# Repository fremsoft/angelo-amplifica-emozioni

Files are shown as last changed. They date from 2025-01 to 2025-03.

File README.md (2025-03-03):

# ANGELO: Amplifica Emozioni

## La Storia
Luciano Fumagalli, pensionato curioso e amante del pensiero laterale, è l’ideatore di ANGELO, un dispositivo inizialmente pensato per gli anziani ipoacusici delle RSA italiane durante la recente pandemia. Grazie alla sua economicità e condivisione Open Source, ANGELO è adatto anche ai paesi LMIC (Low and Low Middle Income Countries), spesso gravati da un elevato grado di inaccessibilità alla tecnologia.

L'idea di ANGELO nasce dalla passione per la tecnologia e dalla sfida di affrontare problematiche sociali, migliorando l'accesso alle cure uditive per anziani e persone in contesti difficili. Luciano ha utilizzato il pensiero laterale per ideare soluzioni non convenzionali, migliorando la qualità della vita di chi ha difficoltà uditive.

---

## Il Team
Il progetto "ANGELO, amplifica emozioni" è stato possibile grazie alla collaborazione di:
- **Docenti universitari**: hanno fornito conoscenze scientifiche e tecnologiche per delineare road map di sviluppo.
- **Scuole superiori**: hanno coinvolto studenti e docenti nella progettazione e realizzazione di prototipi, poi donati alle RSA.
- **Maker audiofilo**: ha contribuito con competenze sugli amplificatori equalizzati.
- **Hub tecnologici e designer**: hanno sviluppato una cover 3D elegante, ergonomica e facile da assemblare.
- **Società di packaging e artista calligrafico**: hanno realizzato un box su misura con design emozionale.

Grazie a queste sinergie, ANGELO è diventato un dispositivo acustico Open Source innovativo e inclusivo.

---

## Il Progetto
ANGELO è un amplificatore equalizzato, progettato per potenziare selettivamente le frequenze uditive rilevanti, migliorando la comprensione del parlato e la percezione delle emozioni sonore.

Caratteristiche principali:
- **Open Source**: flessibile e scalabile, consente la condivisione di conoscenze e l'innovazione continua.
- **Design intuitivo**: facile da assemblare senza strumenti specifici.
- **Inclusività**: mira a migliorare l'accesso alle cure uditive nei paesi LMIC.

Futuri sviluppi includono:
- **Cuffie Bluetooth** per maggiore comodità.
- **Caricatore a celle solari** per comunità senza accesso alla rete elettrica.

---

## Risorse Open Source
Tutti i file per realizzare il vostro ANGELO sono rilasciati con licenza **Creative Commons License CC BY-SA 4.0** e scaricabili gratuitamente da Google Drive:
[**Link ai file Google Drive**](https://drive.google.com/drive/folders/1n9cpKRff9xY9v7kV2mCF5TEvL14Rmp0n?usp=drive_link)

### Contenuto:
- Documento Licenza CC BY-SA 4.0
- Documento Google Drive for ANGELO
- **File Schema Elettrico** (*)
- **File Gerber per PCB** (*)
- **File Pick&Place** (*)
- **File BOM (Bill of Materials)** (*)
- **File .stl per cover 3D**
- **Manuale d’uso**

(*) File da caricare su [JLCPCB](https://jlcpcb.com/) per la realizzazione dei KIT Base e Avanzato.

### KIT disponibili:
- **KIT Base**: assemblaggio in pochi minuti, adatto anche a mani inesperte.
- **KIT Avanzato**: richiede competenze minime in elettronica e stampa 3D, ideale per scuole, FABLAB e associazioni.
- 🛒 **Prodotto acquistabile presso FuturaNet**: (https://futuranet.it/prodotto/dispositivo-acustico/?ref=131015)

---

## Contatti
- **Email**: semprebarnum@gmail.com
- **LinkedIn**: [Luciano Fumagalli](https://linkedin.com/in/luciano-fumagalli-a1a90487)
- **WhatsApp**: +39 331 111 6973

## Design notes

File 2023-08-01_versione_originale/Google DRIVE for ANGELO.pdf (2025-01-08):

## GOOGLE DRIVE

https://drive.google.com/drive/folders/1n9cpKRff9xY9v7kV2mCF5TEvL14Rmp0n?usp=drive_link

ANGELO KIT BASE SMD :

Schematico: Schematic_ANGELO-SMD_CHEAP-V2.0.pdf

PCB | : Gerber_ANGELO-SMD_CHEAP-V2.0.zip
BOM | : BOM_ANGELO-SMD_CHEAP-V2.0.csv

Pick&Place : PickAndPlace_PCB-ANGELO_SMD_CHEP-V2.0.csv

ANGELO KIT AVANZATO Through Hole:

Schematico : Schematic_ANGELO-TH_CHEAP-V2.0.pdf

PCB | : Gerber_ANGELO-TH_CHEAP-V2.0.zip
BOM | : BOM_ANGELO-TH_CHEAP-V2.0.csv

COVER 3D x KIT BASE e AVANZATO

Cover 3D Top : SoprAngeloV2o.stl Cover 3D Bottom : SottAngeloV2o.stl File FUSION360 : TuttAngeloV20.f3d

DOCUMENTAZIONE x KIT BASE e AVANZATO:

ANGELO Manuale d’uso
Licenza CC BY-SA 4.0 (leggere attentamente)

MATERIALE extra File BOM x KIT BASE e AVANZATO:

Potenziometro volume ON/OFF:

https://www.cariatielettronica.eu/it/perno-15mm/3885-potenziometro-lineare-50kohm-b50k-rv097ns-15mm-coninterruttore.html

Manopola potenziometro volume ON/OFF:

https://www.ebay.it/itm/183084248592

Microfono esterno:

https://www.amazon.it/gp/product/B0897PWRZG/ref=ppx_yo_dt_b_search_asin_title?ie=UTF8&psc=1

Capsula microfonica interna:

https://www.amazon.it/AERZETIX-Microfonoomnidirezionale-200-20000Hz-%C3%989-7x6-5mm/dp/B08VWV8X47/

Batteria ENEGON 9V USB Dirette Batteria 650mAh Litio Ricaricabile con Cavo Micro USB 2 :

https://www.amazon.it/ENEGON-Ricaricabile-Microfono-Walkie-talkie-dispositivi/dp/B07VKN5TP9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 -4939-934a-c9057bdc9388%3Aamzn1.sym.252b0043-2859-4939-934a-c9057bdc9388&cv_ct_cx=batteria+usb&keywords=batteria +usb&pd_rd_i=B07VKN5TP9&pd_rd_r=18fce585-f431-45c6-b138-
fe0986e767e1&pd_rd_w=k7uJi&pd_rd_wg=KCxv5&pf_rd_ p=252b0043-2859-4939-934a-c9057bdc9388&pf_rd_r=P3JQCC5AK9HJF44VEBSW&qid =1698831682&sbo=RZvfv%2F%2FHxDF% 2BO5021pAnSA%3D%3D&sr=1-1-1890b328-3a40-4864-baa0-a8eddba1bf6a

Cavetti per microfono INT e connettore batteria ENEGON:

https://www.amazon.it/gp/product/B0CBWYWRQH/ref=ox_sc_act_title_1?smid=A2KWOEY1RHRC64&psc=1

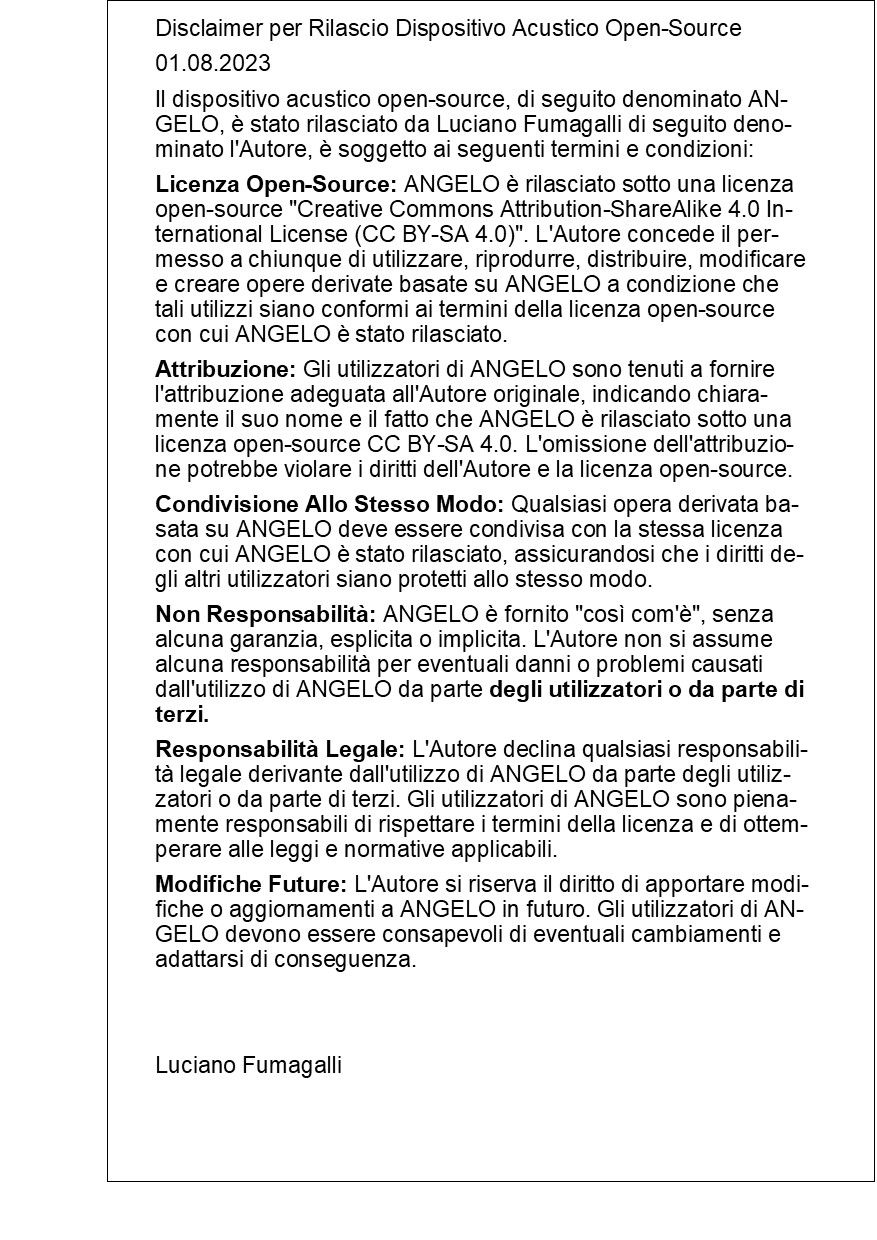
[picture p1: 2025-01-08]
2023-08-01_versione_originale/Licenza CC BY-SA 4.0.jpg

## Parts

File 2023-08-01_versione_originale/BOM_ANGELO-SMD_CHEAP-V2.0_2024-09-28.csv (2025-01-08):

ID | Name | Designator | Footprint | Quantity | Manufacturer Part | Manufacturer | Supplier | Supplier Part | Price
1 | 330n | C1 | C0805 | 1 | EMK212BJ225KG-T | Taiyo Yuden | LCSC | C73142 | 0.011
2 | 10n | C2 | C0805 | 1 | 0805B223K500CT | Huaxin S&T | LCSC | C52278 | 0.004
3 | 470 | R1 | R0805 | 1 | RC0805JR-0747RL | YAGEO | LCSC | C2907329 | 0.001
4 | 10K | R3 | R0805 | 1 | 0805W8F6801T5E | UniOhm | LCSC | C17414 | 0.002
5 | 22uF | C3,C10 | CAP-SMD_BD4.0-L4.3-W4.3-LS5.3-FD | 2 | RVT1A220M0405 | ROQANG | LCSC | C87865 | 0.028
6 | 10uF | C8,C12 | CAP-SMD_BD4.0-L4.3-W4.3-LS5.1-FD | 2 | VE-100M1A0405-TRO | Lelon | LCSC | C249449 | 0.054
7 | 100uF | C5,C14,C15 | CAP-SMD_BD6.3-L6.6-W6.6-FD | 3 | RVE1A101M0605 | HONOR | LCSC | C2963046 | 0.032
8 | S9012 | Q2 | SOT-23-3_L2.9-W1.3-P1.90-LS2.4-BR | 1 | S9012 | BORN(伯恩半导体) | LCSC | C466628 | 0.017
9 | S9013 | Q1 | SOT-23-3_L2.9-W1.3-P1.90-LS2.4-BR | 1 | S9013W | CJ(江苏长电/长晶) | LCSC | C2688220 | 0.012
10 | 220u | C9 | CAP-SMD_BD6.3-L6.6-W6.6-FD | 1 | XT220UF10V90RV0073 | Changzhou Huawei Elec | LCSC | C2992604 | 0.029
11 | PJ-3655-SMT | SK1,SK2 | AUDIO-SMD_PJ-3655-SMT | 2 | PJ-3655-SMT | XKB Enterprise | LCSC | C397344 | 0.249
12 | 0.1u | C4,C6,C11,C13 | C0805 | 4 | 0805B104K500 | WTC | LCSC | C83055 | 0.005
13 | 4.7n | C7 | C0805 | 1 | 0805B104K500 |  | LCSC | C396760 | 0.027
14 | LED ON | DL1 | LED-TH_BD3.0-P2.54-FD | 1 | HL-304S9AD | HONGLITRONIC(Hongli Zhihui (HONGLITRONIC)) | LCSC | C568936 | 0.044
15 | MIC INT | J1 | CONN-TH_2P-P2.50_XKB_X8821WV-02-N0SN | 1 | X8821WV-02-N0SN | XKB Connectivity(中国星坤) | LCSC | C2884141 | 0.014
16 | Battery | J2 | CONN-TH_2P-P2.50_XKB_X8821WV-02-N0SN | 1 | X8821WV-02-N0SN | XKB Connectivity(中国星坤) | LCSC | C2884141 | 0.014
17 | TL072IP | U1 | SOIC-8_150MIL | 1 | TL072CDT | TI | LCSC | C6961 | 0.137
18 | LM386N | U2 | SOIC-8_150MIL | 1 | LM386MX-1/NOPB | TI | LCSC | C23573 | 0.352
19 | 2.2K | R2 | R0805 | 1 | 0805W8F2201T5E | UniOhm | LCSC | C17520 | 0.002
20 | 10K | R4,R9,R10 | R0805 | 3 | RS-05K103JT | FH | LCSC | C115295 | 0.002
21 | 50K | R5 | R0805 | 1 | AR05BTCW5002 | Viking Tech | LCSC | C316211 | 0.038
22 | 100 | R6 | R0805 | 1 | RS-05K101JT | FH | LCSC | C115423 | 0.001
23 | 50K | R7 | 5PIN RV097NS | 1
24 | 1k | R8 | R0805 | 1 | 0805W8F1001T5E | UniOhm | LCSC | C17513 | 0.002

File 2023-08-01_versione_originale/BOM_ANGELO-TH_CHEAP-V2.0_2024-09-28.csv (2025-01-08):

ID | Name | Designator | Footprint | Quantity | Manufacturer Part | Manufacturer | Supplier | Supplier Part | Price
1 | 330n | C1 | CAP-TH_L5.0-W2.5-P5.08-D0.7 | 1 | 225K-100V-1206 |  | LCSC | C454409 | 0.147
2 | 10n | C2 | CAP-TH_L5.0-W2.5-P5.08-D0.7 | 1 | CC1H223ZC1SD3F4D30MF | Dersonic | LCSC | C254084 | 0.011
3 | 470 | R1 | R_AXIAL-0.4 | 1 | MF1/8W-47Ω±1%-OT52 | VO | LCSC | C2848526 | 0.002
4 | 10k | R3 | R_AXIAL-0.4 | 1 | MFR-25FTE52-6K8 | YAGEO | LCSC | C5249395 | 0.007
5 | 0.1u | C4,C6,C11,C13 | CAP-TH_L5.0-W2.5-P5.08-D0.7 | 4 | K104K15X7RF5TH5 |  | LCSC | C2167231 | 0.053
6 | 4.7n | C7 | CAP-TH_L5.0-W2.5-P5.08-D0.7 | 1 | CC1H472MA1FDF44B1000 | Dersonic | LCSC | C377838 | 0.004
7 | 220u | C9 | CAP-D6.3-F2.5 | 1 | 25V220uF CD288 |  | LCSC | C2960221 | 0.023
8 | MIC INT | J1 | CONN-TH_2P-P2.50_XKB_X8821WV-02-N0SN | 1 | X8821WV-02-N0SN | XKB Connectivity(中国星坤) | LCSC | C2884141 | 0.014
9 | 2.2K | R2 | R_AXIAL-0.4 | 1 | MFR50SJT-52-2K2 | YAGEO | LCSC | C176635 | 0.018
10 | 10K | R4,R9,R10 | R_AXIAL-0.4 | 3 | CFR25SJT-52-10K | YAGEO(国巨) | LCSC | C1369217 | 0.01
11 | 51K | R5 | R_AXIAL-0.4 | 1 | MFR-25JT-52-51K | YAGEO | LCSC | C176525 | 0.01
12 | 100 | R6 | R_AXIAL-0.4 | 1 | MFR0W4F1000A50 | UniOhm | LCSC | C57438 | 0.01
13 | TL072IP | U1 | PDIP-8_L10.2-W5.9-P2.54-LS7.6-BL | 1 | TL072IP | TI | LCSC | C110329 | 0.712
14 | LM386N | U2 | PDIP-8_L10.2-W5.9-P2.54-LS7.6-BL | 1 | LM386N-1 | HGSEMI(华冠) | LCSC | C2835213 | 0.133
15 | 22u | C3,C10 | CAP-D4.0-F1.5 | 2 | SM1061CMB072RB | Xunda | LCSC | C399141 | 0.012
16 | 100u | C5,C14,C15 | CAP-D6.3-F2.5 | 3 | 25V100uF CD110 | HRK(鸿瑞凯电子) | LCSC | C2960218 | 0.014
17 | 10u | C8,C12 | CAP-D4.0-F1.5 | 2 | SM1061CMB072RB |  | LCSC | C399141 | 0.012
18 | 50K | R7 | 5PIN RV097NS | 1 |  |  | Cariati Elettronica | RV097NS
19 | PJ-3655-SMT | SK1,SK2 | AUDIO-SMD_PJ-3655-SMT | 2 | PJ-3655-SMT | XKB Enterprise | LCSC | C397344 | 0.249
20 | Battery | J2 | CONN-TH_2P-P2.50_XKB_X8821WV-02-N0SN | 1 | X8821WV-02-N0SN | XKB Connectivity(中国星坤) | LCSC | C2884141 | 0.014
21 | 1k | R8 | R_AXIAL-0.4 | 1 | MFR0W4F1001A50 | UniOhm | LCSC | C57435 | 0.011
22 | S9013 | Q1 | TO-92-3_L4.9-W3.7-P1.27-L | 1 | S9013 | CJ(江苏长电/长晶) | LCSC | C16066 | 0.026
23 | S9012 | Q2 | TO-92-3_L4.9-W3.7-P1.27-L | 1 | S9012 | CJ(江苏长电/长晶) | LCSC | C147853 | 0.026
24 | LED ON | DL1 | LED-TH_BD3.0-P2.54-FD | 1 | HL-304S9AD | HONGLITRONIC(Hongli Zhihui (HONGLITRONIC)) | LCSC | C568936 | 0.044

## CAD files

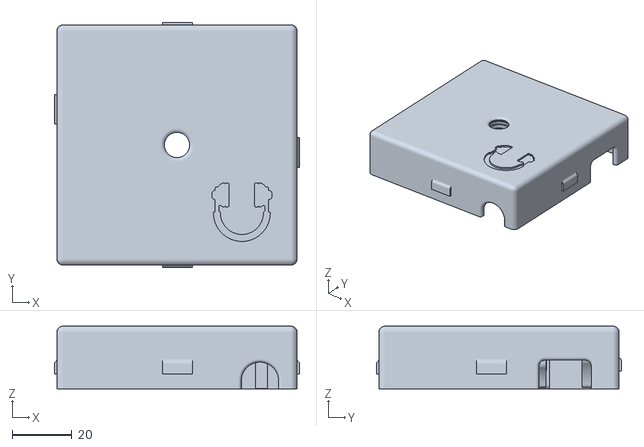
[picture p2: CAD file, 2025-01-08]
2023-08-01_versione_originale/SoprAngeloV2o.stl
82.1 x 82.1 x 21.0

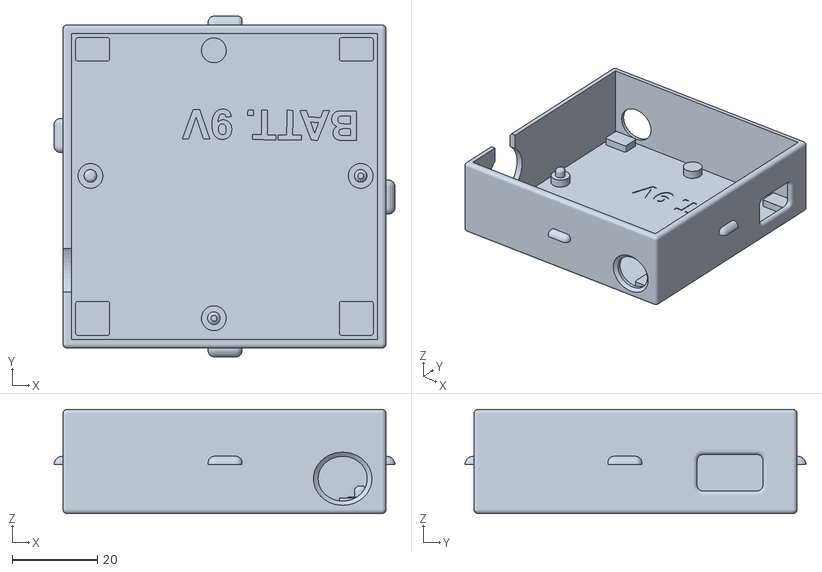
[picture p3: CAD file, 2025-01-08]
2023-08-01_versione_originale/SottAngeloV2o.stl
80.2 x 80.2 x 24.5

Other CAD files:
2023-08-01_versione_originale/TuttAngeloV2o.f3d

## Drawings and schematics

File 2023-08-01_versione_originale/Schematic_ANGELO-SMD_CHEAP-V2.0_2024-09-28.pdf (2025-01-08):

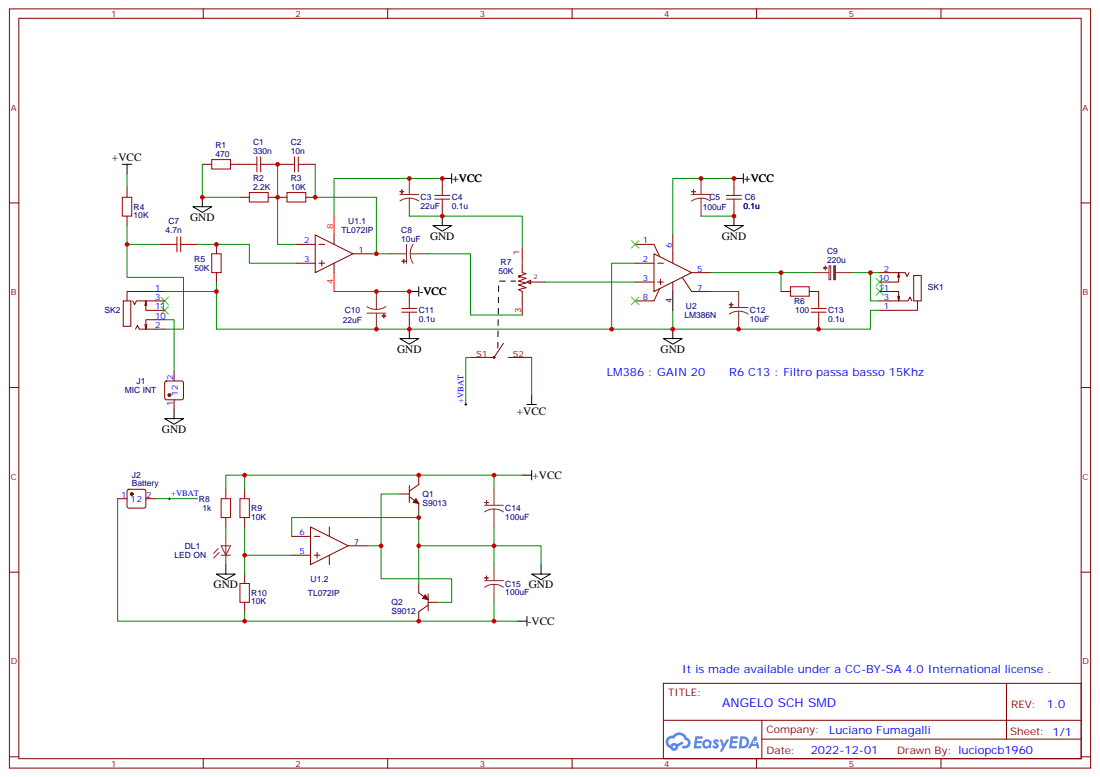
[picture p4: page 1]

It is made available under a CC-BY-SA 4.0 International license .
TITLE:

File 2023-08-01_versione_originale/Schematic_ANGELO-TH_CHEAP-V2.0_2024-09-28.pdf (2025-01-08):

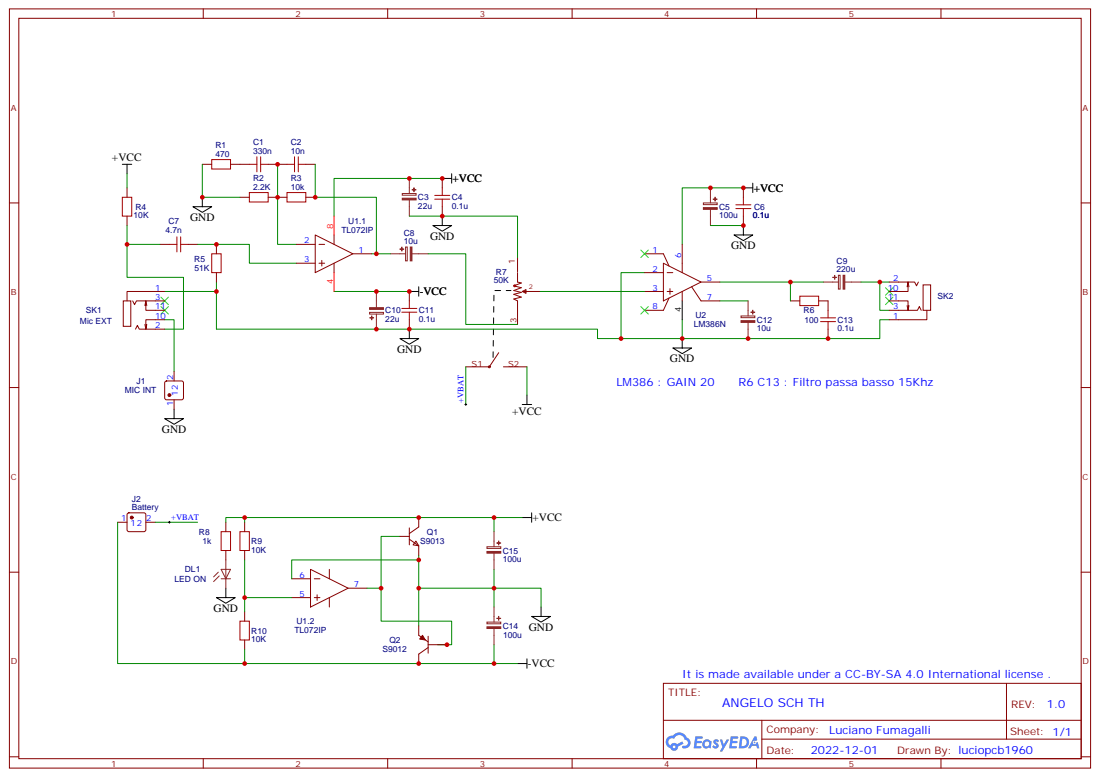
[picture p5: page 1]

It is made available under a CC-BY-SA 4.0 International license .
TITLE:

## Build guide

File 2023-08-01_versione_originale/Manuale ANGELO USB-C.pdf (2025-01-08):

ANGELO,

# amplifica emozioni

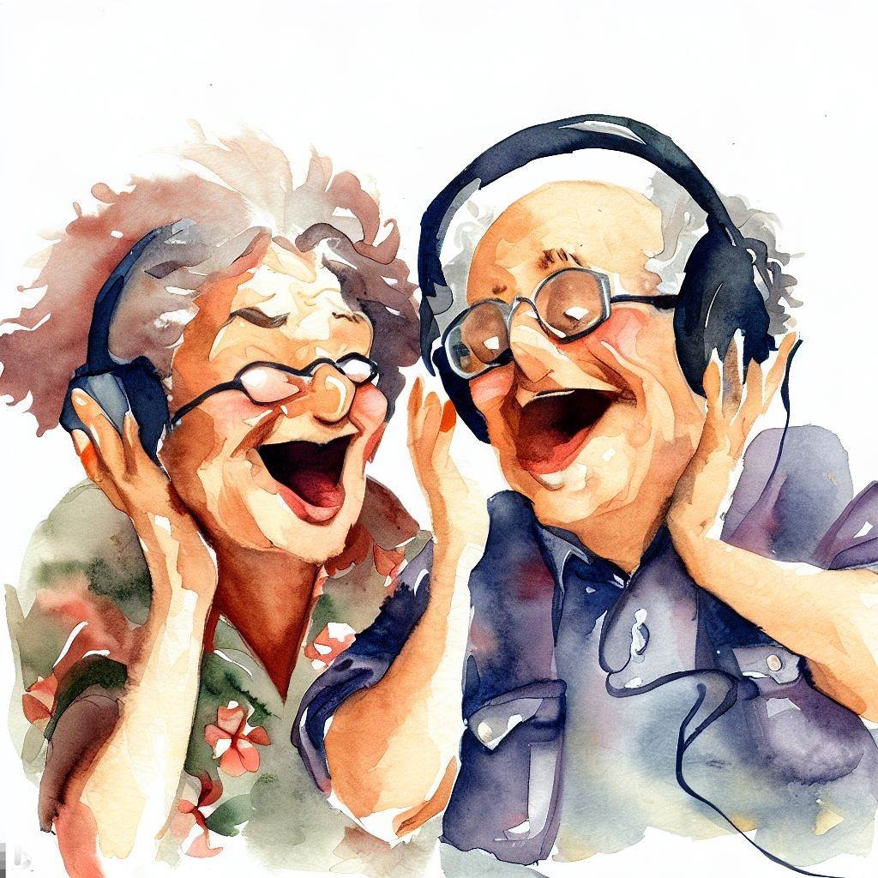
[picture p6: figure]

Benvenuti nel meraviglioso mondo di ANGELO, il cuore di un'eccezionale collaborazione tra docenti universitari, designer, un laboratorio innovativo, una scuola, un artista e un maker audiofilo.

Questo dispositivo acustico è progettato per avvolgere le persone ipoacusiche delle RSA italiane e della popolazione dei paesi a basso e medio reddito (LMIC) con una calda melodia di empatia e connessione emotiva.

Ogni nota racchiude la dedizione di talenti eterogenei che si sono uniti per creare un'esperienza uditiva immersiva.

Grazie ad ANGELO, ogni suono, ogni risata e ogni voce si trasformano in preziose emozioni condivise, arricchendo le vite di coloro che spesso si sentono distanti dal mondo sonoro.

La sua anima aperta e accessibile, grazie all'approccio Open Source, suggella il suo impegno nel raggiungere tutti coloro che hanno bisogno di un abbraccio sonoro.

Con ANGELO, la musica dell'anima si fonde con la tecnologia del cuore, trasformando il silenzio in una partitura che si compone e si scompone, dando vita a nuovi mondi sonori.

Con ogni nota, noi siamo ANGELO, e ANGELO è noi.

Buone emozioni!

A

D | B

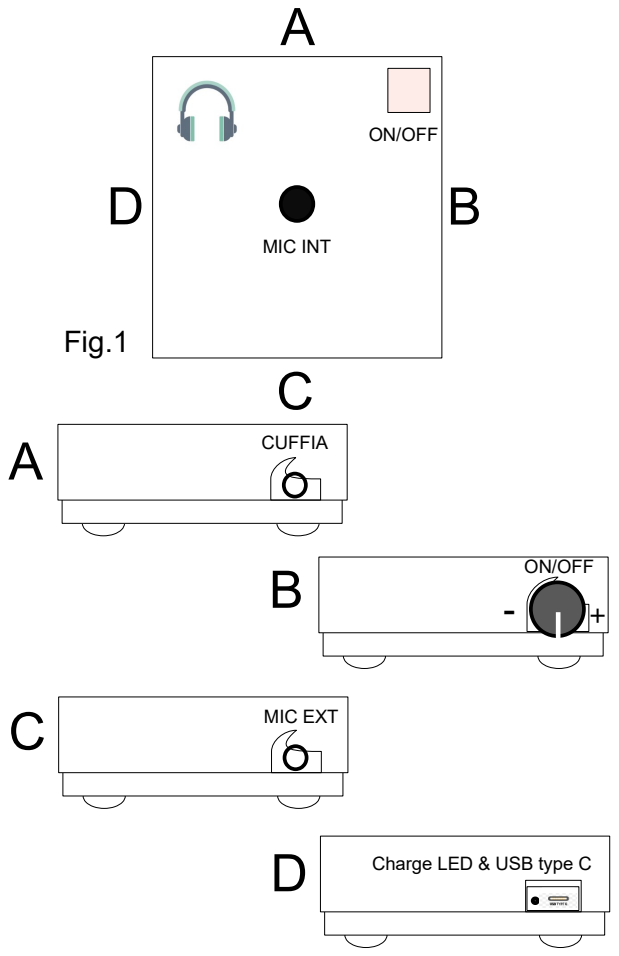
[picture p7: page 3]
CUFFIA A; ON/OFF B - +; MIC EXT C; MIC INT; ON/OFF; Fig.1

Charge LED & USB type C D

Fig.2 | Fig.3

## Fig.4 (it’s coming) Cavo M/M 3.5mm

## (it’s coming)

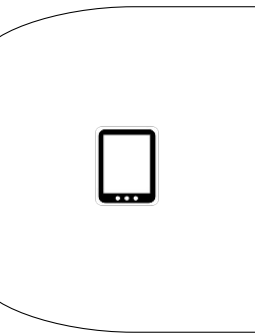
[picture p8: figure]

LEGENDA

La Fig.1 visualizza le connessioni e le funzionalità di
di ANGELO presenti sui quattro lati laterali e il superiore.

TIPOLOGIE DI CONNESSIONE

La Fig.2 visualizza la funzionalità di ANGELO con il microfono interno (MIC INT).

La Fig.3 visualizza la funzionalità di ANGELO con il microfono esterno (MIC EXT).

La Fig.4 visualizza la funzionalità di ANGELO connesso a dispositivi esterni come smartphone, tablet o radio
e sviluppi futuri (it’s coming).

RICARICA via USB

Inserire il cavetto del caricatore USB-C nel connettore sul Lato D.
La lucina ROSSA vicina al connettore di ricarica USB-C indica la fase di ricarica della batteria interna, quando questa sarà carica la lucina diverrà BLU.
Scollegare il cavetto del caricatore USB-C prima di utilizzare ANGELO.

ATTENZIONE

Non utilizzare ANGELO con il caricatore USB-C connesso al fine di evitare fastidiosi ronzii. Usare solo caricatori
USB-C ( | ).

Assicurarsi prima di utilizzare le cuffie che ANGELO sia spento (manopola volume Lato B ruotata tutta in senso antiorario sino a udire il classico click e la spia luminosa ON/OFF sul lato superiore spenta.

Lo spinotto della cuffia va inserito nel jack sul Lato A, se erroneamente lo si inserisce sul Lato C del microfono esterno NON SUCCEDE NULLA, non preoccupatevi, inseritelo correttamente e buone emozioni.

La durata della carica consente di amplificare moltissime emozioni, l’importante è ricordarsi a fine utilizzo di spegnere ANGELO riportando la manopola del volume tutta in senso antiorario sino a udire il classico click e la spia luminosa sul lato superiore ON/OFF spenta.

Al fine di un corretto utilizzo, assicurarsi sempre di inserire completamente spinotti e cavetti in funzione della operatività selezionata (vedi Fig.2/Fig.3/Fig.4).

E’ importantissimo posizionare le cuffie in modo da risultare confortevoli (aiutandosi con il soffietto che consente una personalizzazione della misura del capo) e nel contempo isolarsi al meglio dai rumori esterni.

SUGGERIMENTI

Se inserisco il cavetto del microfono esterno (MIC EXT sul Lato C) si esclude il microfono interno (MIC INT sul lato superiore)
e viceversa.

Con il microfono interno (MIC INT– Fig.2) il dispositivo ANGELO cattura le voci e i rumori dell'ambiente, per tale ragione se utilizzato in ambienti rumorosi si consiglia di utilizzare il microfono esterno (MIC EXT-Fig.3) che amplifica al meglio la voce dell'interlocutore riducendo il rumore ambientale.

Ricordarsi che l'ospite è isolato dai suoni e dalle voci esterne dalla cuffia ragion per cui evitare di parlargli senza il microfono o addirittura fuori dal suo campo visivo, porsi di fronte a lui, guardarlo negli occhi e se possibile concedergli la lettura del labiale e ovviamente scandire bene le parole.

Evitare per quanto possibile durante la conversazione di muovere i fili della cuffia o picchiettare sul corpo del dispositivo o sul microfono esterno, si consiglia di porre la cuffia sul capo, porre su di un tavolo o un supporto stabile ANGELO e, se presente, fissare il microfono esterno con l'apposita clip al proprio colletto direzionato verso la bocca e poi iniziare la conversazione.

Disclaimer per Rilascio Dispositivo Acustico Open-Source 01.08.2023
Il dispositivo acustico open-source, di seguito denominato ANGELO, è stato rilasciato da Luciano Fumagalli di seguito denominato l'Autore, è soggetto ai seguenti termini e condizioni: Licenza Open-Source: ANGELO è rilasciato sotto una licenza open-source "Creative Commons Attribution-ShareAlike 4.0 International License (CC BY-SA 4.0)". L'Autore concede il permesso a chiunque di utilizzare, riprodurre, distribuire, modificare e creare opere derivate basate su ANGELO a condizione che tali utilizzi siano conformi ai termini della licenza open-source con cui ANGELO è stato rilasciato.
Attribuzione: Gli utilizzatori di ANGELO sono tenuti a fornire l'attribuzione adeguata all'Autore originale, indicando chiaramente il suo nome e il fatto che ANGELO è rilasciato sotto una licenza open-source CC BY-SA 4.0. L'omissione dell'attribuzione potrebbe violare i diritti dell'Autore e la licenza open-source.
Condivisione Allo Stesso Modo: Qualsiasi opera derivata basata su ANGELO deve essere condivisa con la stessa licenza con cui ANGELO è stato rilasciato, assicurandosi che i diritti degli altri utilizzatori siano protetti allo stesso modo.
Non Responsabilità: ANGELO è fornito "così com'è", senza alcuna garanzia, esplicita o implicita. L'Autore non si assume alcuna responsabilità per eventuali danni o problemi causati dall'utilizzo di ANGELO da parte degli utilizzatori o da parte di terzi.
Responsabilità Legale: L'Autore declina qualsiasi responsabilità legale derivante dall'utilizzo di ANGELO da parte degli utilizzatori o da parte di terzi. Gli utilizzatori di ANGELO sono pienamente responsabili di rispettare i termini della licenza e di ottemperare alle leggi e normative applicabili.
Modifiche Future: L'Autore si riserva il diritto di apportare modifiche o aggiornamenti a ANGELO in futuro. Gli utilizzatori di ANGELO devono essere consapevoli di eventuali cambiamenti e adattarsi di conseguenza.

Luciano Fumagalli

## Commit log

2025-01-08 versione originale
    [BOM_ANGELO-SMD_CHEAP-V2.0_2024-09-28.csv, BOM_ANGELO-TH_CHEAP-V2.0_2024-09-28.csv, PickAndPlace_PCB-ANGELO_SMD_CHEAP-V2.0_2024-09-28.csv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]
2025-01-08 versione originale del 1-8-2023
    [BOM_ANGELO-SMD_CHEAP-V2.0_2024-09-28.csv, BOM_ANGELO-TH_CHEAP-V2.0_2024-09-28.csv, PickAndPlace_PCB-ANGELO_SMD_CHEAP-V2.0_2024-09-28.csv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]
